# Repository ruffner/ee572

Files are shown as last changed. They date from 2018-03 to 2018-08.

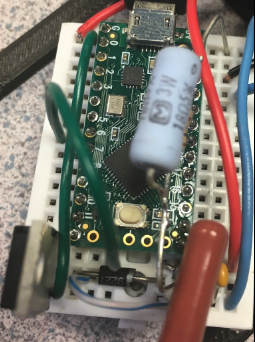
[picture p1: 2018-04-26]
project/Images/pic2.png

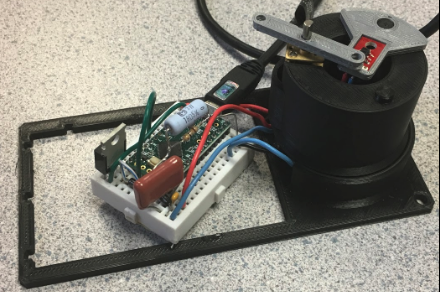
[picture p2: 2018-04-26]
project/Images/pic1.png

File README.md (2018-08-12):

# ee572

Home for EE572 Coursework, Digital Control of Dynamic Systems at the University of Kentucky. 
- [READ WRITEUP](https://github.com/ruffner/ee572/blob/master/project/ee572-project.pdf)
- Created an embedded implementation of a PID compensator. The body design from the [feedback strobe](http://github.com/ruffner/feedback-strobe) was modified to have higher rotation speed.
- RPM calculation done with [infrared reflectance sensor](https://www.sparkfun.com/products/9453).
- Code available in writeup

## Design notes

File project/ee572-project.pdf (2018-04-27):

# EE572 Course Project

### Matt Ruffner Alex Mueller Ben Cummins Galvin Greene

### April 27, 2018

## 1 Objective

A physical control system allows the team to apply class concepts to the real world. These include continuous/discrete time modeling and compensation techniques. With a working system, the team has demon-strated competency in controls theory. For this project the team used a Teensy LC 1 ARM microcontroller to implement a PID compensator. The system manages the speed of a DC motor with a propeller like attachment. Simulations were run in MATLAB to help design the PID compensator.

## 2 Continuous Time System

In order to fully control our chosen system, the team first had to analyze and decide on a G(s) model that would represent the system. The team had brief discussion and the chosen model can be seen from equation 1.

G(s) = K
1 + 0.5τs

(1)

Within this model, K represents the max speed, in RPM, that our motor can physically move, represents the time it took to move from the lowest to the highest. These variables were found by testing and measuring the system. Now that the G(s) has been determined, the team had to create a Zero Order Hold model for our system, which can be seen from equation 2

GZOH(s) = 1 1 + sTs

2

(2)

This representation for the Zero Order Hold is used to properly model the system in continuous time and simulate the discrete measurements. This model relies on a Ts and was chosen to be .1 seconds. The final model needed for the system is a compensation model to allow the team to alter the system to specific specs. For this the team chose a PID model and can be seen from equation 3

GP ID(s) = Ki + sKp + s

2Kd
| s

(3)

This model for the PID compensation requires the team to solve for Ki
, Kp, and Kd and is completed by determining an s1 that meets given transient specs and finding a Zc and a Kc by computing coefficients. For this model we used equation 4, because the team had no steady state error specs and thus could improve transient specs.

1https://www.pjrc.com/teensy/teensyLC.html

1

GP ID(s) = s

2Kc + 2sZcKc + KcZ

2
c

(4)

Where
Kd = Kc

Kp = 2KcZc

Ki = KcZ

2
c
Once these values were calculated and implemented into the equation, the team could then close the loop for the continuous time model by using equation 5. This is an important part of simulation as it shows how the system should react in real time and whether the transient specs were truly met and if needed, further optimized.

Gclosedloop(s) = GP ID(s)GZOH(s)G(s)
1 + GP ID(s)GZOH(s)G(s)

(5)

Additionally, if observed from the top level, the system would appear as Figure 1.

Figure 1: Continuous time system model

For a complete list of our given specs and those values that were solved for/calculated in MATLAB, see Table 1.

Parameter | Value
Ts | 0.1 seconds
τ | 8 seconds
Mp | 4.32%
ts | 1 second
s1 | -4+j3.996
K | 810
ωnζ | 4
ωn | 5.6566
ζ | 0.707
6 def. | 103.314◦
Zc | 7.1739
Kc | 0.0334
Ki | 1.7173
Kp | 0.4787
Kd | 0.0334

Table 1: System parameters

2

## 3 Discrete Time Compensator

The discrete compensator was found by using continuous version and substituting an estimate for s in terms of z. Our estimate was
s =

z − 1
zTs
which is a rectangular approximation from the right side. The bilinear transform was not used because it would have placed a pole at z = −1 when substituting in s with the Kd term. Using MATLAB we found

HP ID(z) = 3.546e17z

2 − 4.129e17z + 1.202e17
3.603e17z

2 − 3.603e17z
Simplifying the coefficients gives values of a0 = 1, a1 = −1, a2 = 0, b0 = 0.9842, b1 = −1.1461, b2 = 0.3337 for our second order filter to be implemented in microcontroller code.

## 4 MATLAB Simulation

This section contains plots of simulation data from designing the system in MATLAB.
Figure 2 shows the system’s step response before compensation. Figure 3 shows the step response of the compensated system.
Figure 4 shows the system’s step response before compensation. Figure 5 shows the step response of the compensated system.

## 5 Implementation

A simple geared down DC brushed motor is driven by a the Teensy LC microcontroller over USB power. Flyback diodes for reverse EMF protection and noise filtering circuitry are also included.
The second order PID filter was implemented the same way that was taught in EE572 lecture. The general form of the filter is shown in Equation 6.

Y (z)
W(z)

=

b0 + b1z

−1 + b2z

−2
a0 + a1z⁻¹ + a2

−2
z

(6)

The coefficients were computed in MATLAB, but taking the inverse z transform and rearranging to solve for yk, our output, gave a new equation that could be written in code:

yk=(b0*wk+b1*wk_minus1+b2*wk_minus2-a1*yk_minus1-a2*yk_minus2)/(a0)

Update equations were also needed to change the values after each iteration. These were as follows:

wk=Setpoint-rpm;
wk_minus2=wk_minus1;
wk_minus1=wk;
yk_minus2=yk_minus1;
yk_minus1=yk;

### 5.1 Feedback

Feedback on the rotation speed of the system is provided by an IR reflectance sensor. When the propeller passes over the sensor the output voltage dips. These dips are monitored with an ADC channel and detected with thresholding logic in software. The interrupt routine responsible for accurately determining the current RPM of the motor has a much high sampling rate than the control system that uses this information.

3

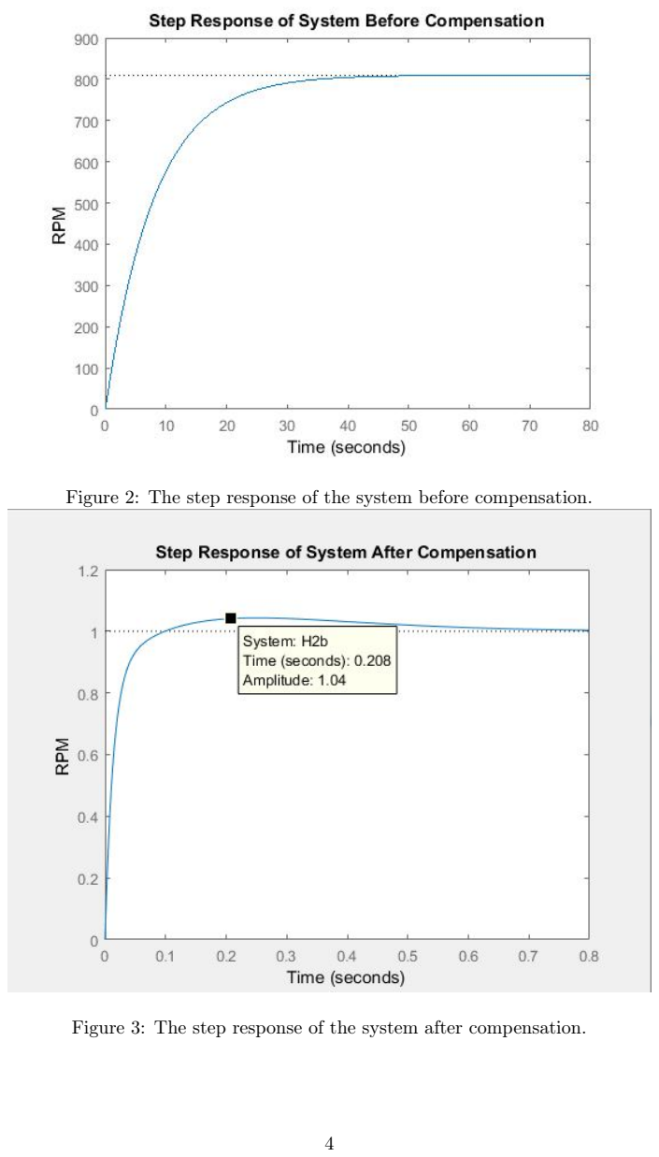
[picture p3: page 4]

Figure 2: The step response of the system before compensation.

Figure 3: The step response of the system after compensation.

4

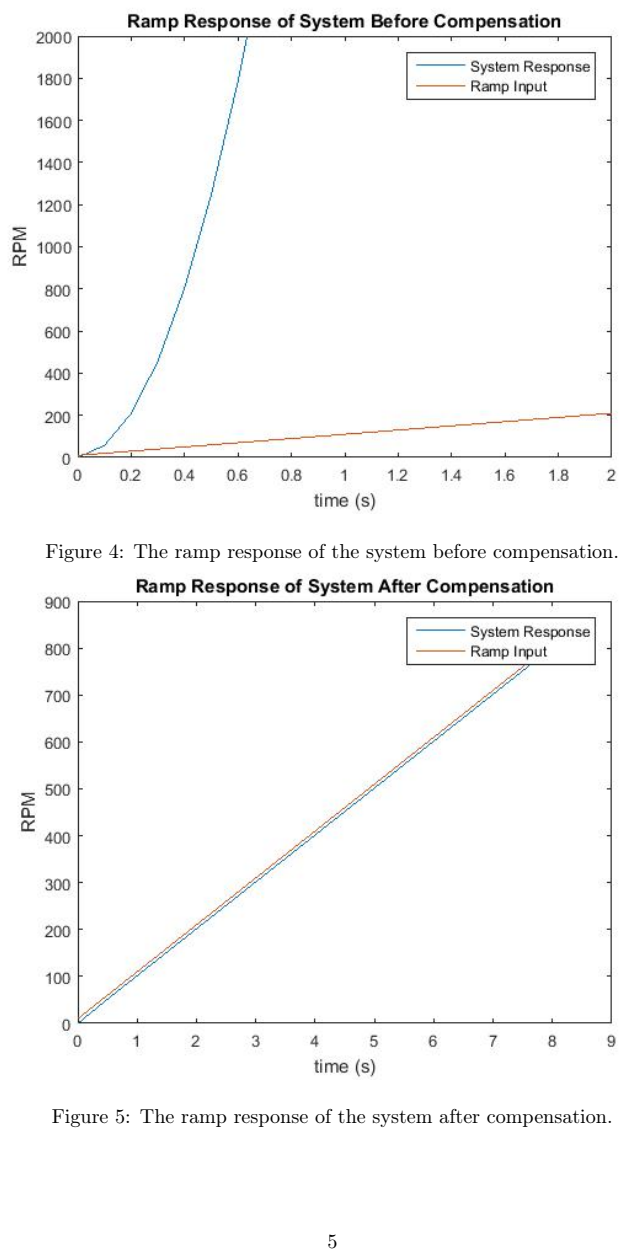
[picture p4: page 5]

Figure 4: The ramp response of the system before compensation.

Figure 5: The ramp response of the system after compensation.

5

The protection circuity was modified from the schematic seen in Figure 6

2 and only includes one MOS-FET.

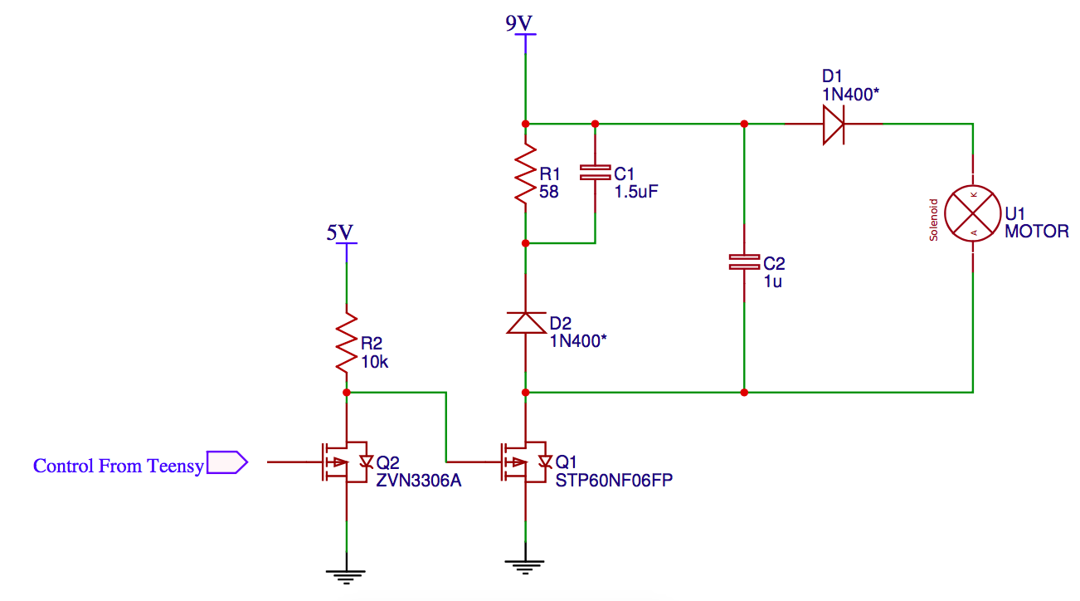
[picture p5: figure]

Figure 6: Back EMF protection circuitry.

### 5.2 Mechanical Design

One key aspect of the code was taking input from the analog reflectance sensor to compute the current RPM of the system. This was achieved by calling the millis() function in conjunction with interrupts from the TimerOne library. RPM values calculated using this method were used as part of the feedback of the system to compare to the setpoint.

### 5.3 Finished System

### 5.4 Plot of Compensation during Setpoint Change

The plot in Figure 8 shows a plot of the desired speed in comparison to the set speed with data logged from the device. This verifies the desired 1 second settling time that we improved from the original settling time of over ten seconds.
The plot in Figure 9 shows the Wk and Yk values during the same run as in Figure 8.

### 5.5 Plot of Compensation During Loading Down of Motor

Figures 10 and 11 show the response of the device under loading conditions e.g. hand on motor shaft. The plot in Figure 9 shows the Wk and Yk values during the same run as in Figure 8.

### 5.6 Ramp Following

Figure 12 shows the real system following a ramp.

2github.com/ruffner/feedback-strobe

6

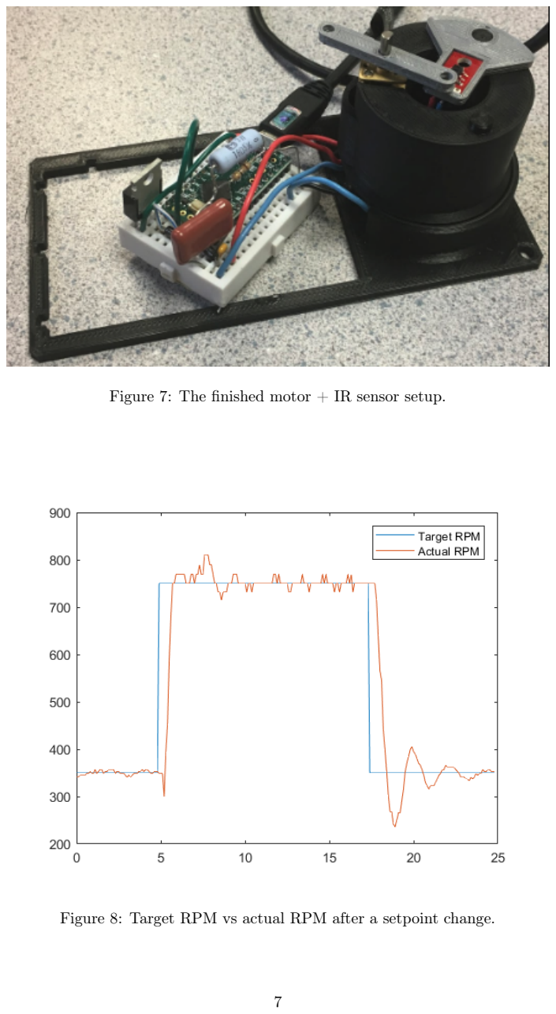
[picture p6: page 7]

Figure 7: The finished motor + IR sensor setup.

Figure 8: Target RPM vs actual RPM after a setpoint change.

7

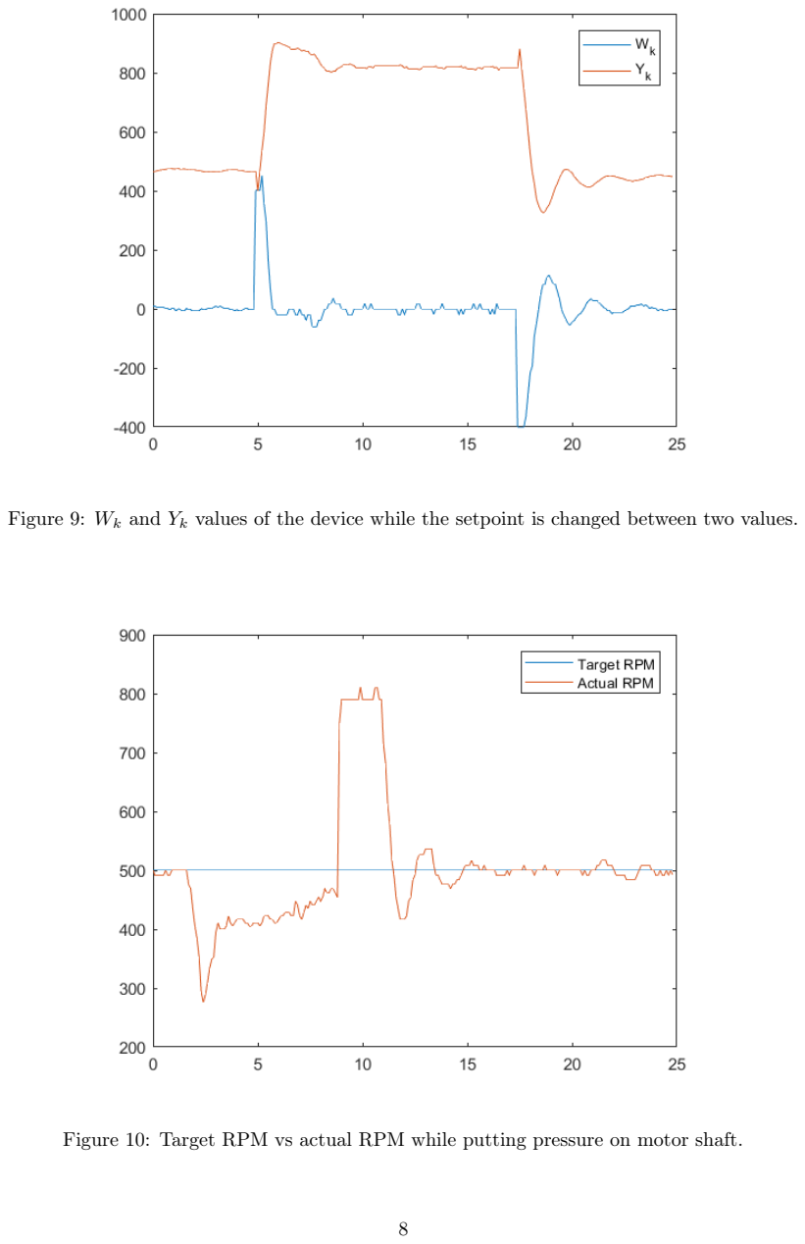
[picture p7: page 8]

Figure 9: Wk and Yk values of the device while the setpoint is changed between two values.

Figure 10: Target RPM vs actual RPM while putting pressure on motor shaft.

8

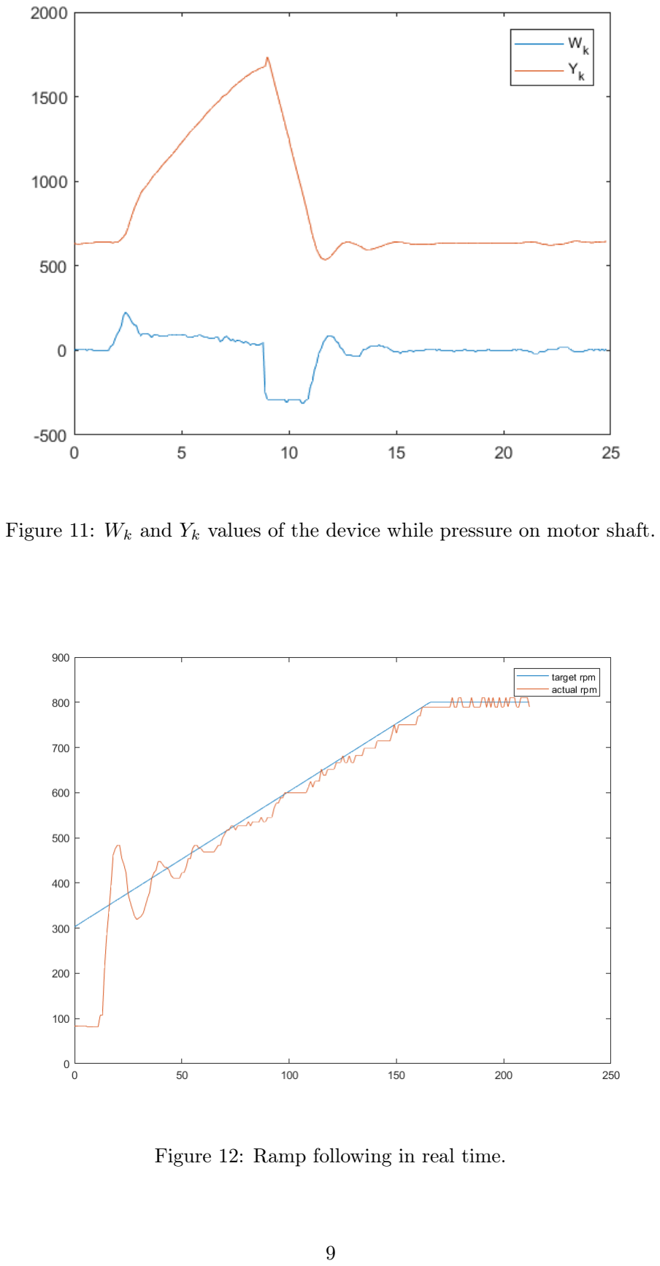
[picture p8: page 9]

Figure 11: Wk and Yk values of the device while pressure on motor shaft.

Figure 12: Ramp following in real time.

9

## 6 Contributions

### 6.1 Alex Mueller

Preliminary brainstorming and MATLAB Code.

### 6.2 Matt Ruffner

Mechanical design, Arduino coding.

### 6.3 Benjamin Cummins

MATLAB coding and brainstorming.

### 6.4 Galvin Greene

Debugged MATLAB and Arduino code.

## 7 References

Code can be found at: https://github.com/ruffner/ee572/tree/master/project

## 8 Arduino Code

// EE572 control system
// Matt Ruffner
// Alex Mueller
// Ben Cummins
// Galvin Greene

#include <TimerOne.h>

#define IRPIN A9

#define MOTOR 6

// MOTOR PWM VALUES WERE ITERATED THROUGH, WITH THE CORRESPONDING RESULTING // RPM VALUE LOGGED. THESE VALUES WERE LOADED INTO MATLAB AND FIT WITH A // POLYNOMIAL. THE FOLLOWING ARRAY IS THE POLYNOMIAL EVALUATED AT VARIOUS // PWM VALUES TO GET A SMOOTHER SPEED CURVE.
// CODE TO GENERATE THIS TABLE CAN BE FOUND IN speed_fit.m in the
// EE572 REPOSITORY

PROGMEM float RPMMap[175] = { 2.847108e+02,2.918626e+02,2.989418e+02,3.059491e+02,3.128849e+02, 3.197497e+02,3.265440e+02,3.332684e+02,3.399233e+02,3.465093e+02, 3.530267e+02,3.594762e+02,3.658583e+02,3.721733e+02,3.784219e+02, 3.846046e+02,3.907218e+02,3.967740e+02,4.027618e+02,4.086856e+02, 4.145460e+02,4.203434e+02,4.260784e+02,4.317514e+02,4.373630e+02, 4.429136e+02,4.484038e+02,4.538341e+02,4.592049e+02,4.645168e+02, 4.697702e+02,4.749657e+02,4.801038e+02,4.851849e+02,4.902096e+02, 4.951784e+02,5.000917e+02,5.049501e+02,5.097541e+02,5.145042e+02,

10

5.192008e+02,5.238446e+02,5.284359e+02,5.329753e+02,5.374632e+02, 5.419003e+02,5.462870e+02,5.506237e+02,5.549110e+02,5.591495e+02, 5.633395e+02,5.674816e+02,5.715763e+02,5.756241e+02,5.796255e+02, 5.835810e+02,5.874911e+02,5.913564e+02,5.951772e+02,5.989541e+02, 6.026877e+02,6.063783e+02,6.100266e+02,6.136330e+02,6.171979e+02, 6.207221e+02,6.242058e+02,6.276496e+02,6.310541e+02,6.344197e+02, 6.377469e+02,6.410363e+02,6.442882e+02,6.475033e+02,6.506821e+02, 6.538249e+02,6.569324e+02,6.600051e+02,6.630433e+02,6.660478e+02, 6.690188e+02,6.719570e+02,6.748628e+02,6.777368e+02,6.805794e+02, 6.833912e+02,6.861726e+02,6.889242e+02,6.916464e+02,6.943398e+02, 6.970049e+02,6.996421e+02,7.022519e+02,7.048349e+02,7.073916e+02, 7.099224e+02,7.124279e+02,7.149086e+02,7.173649e+02,7.197974e+02, 7.222066e+02,7.245930e+02,7.269570e+02,7.292992e+02,7.316201e+02, 7.339201e+02,7.361999e+02,7.384598e+02,7.407004e+02,7.429222e+02, 7.451256e+02,7.473113e+02,7.494796e+02,7.516312e+02,7.537664e+02, 7.558858e+02,7.579900e+02,7.600793e+02,7.621543e+02,7.642155e+02, 7.662634e+02,7.682985e+02,7.703214e+02,7.723324e+02,7.743322e+02, 7.763211e+02,7.782998e+02,7.802686e+02,7.822282e+02,7.841790e+02, 7.861216e+02,7.880563e+02,7.899838e+02,7.919044e+02,7.938189e+02, 7.957275e+02,7.976308e+02,7.995294e+02,8.014237e+02,8.033143e+02, 8.052016e+02,8.070861e+02,8.089683e+02,8.108488e+02,8.127280e+02, 8.146065e+02,8.164847e+02,8.183632e+02,8.202424e+02,8.221228e+02, 8.240050e+02,8.258894e+02,8.277766e+02,8.296671e+02,8.315613e+02, 8.334597e+02,8.353629e+02,8.372714e+02,8.391856e+02,8.411061e+02, 8.430334e+02,8.449679e+02,8.469102e+02,8.488608e+02,8.508201e+02, 8.527887e+02,8.547670e+02,8.567557e+02,8.587551e+02,8.607658e+02, 8.627883e+02,8.648230e+02,8.668706e+02,8.689314e+02,8.710060e+02 };

// VARS FOR DETERMINING CURRENT RPM
unsigned long lastFreqUpdate = 0; float rpm = 0;
int state = 0;
unsigned long lastLowTime = 0; volatile unsigned long diffTime = 0;

// CONTROL PARAMETER
double Setpoint;

// PID STATE VARS
float yk=0.0;
float yk_minus1=0.0;
float yk_minus2=0.0;
float wk=0.0;
float wk_minus1=0.0;
float wk_minus2=0.0;

// PID TF COEFFICIENTS
float b0=0.9842;
float b1=-1.1461;
float b2=0.3337;

11

float a0=1.0;
float a1=-1.0;
float a2=0.0;

unsigned long startTime = 0;

void setup() {
// PIN DIRECTION DEFINITIONS pinMode(IRPIN, INPUT);
pinMode(MOTOR, OUTPUT);
pinMode(13, OUTPUT); // LED

Serial.begin(115200);
delay(2000);

// RPM SENSING SETUP
// 1 MILLISECOND SAMPLING PERIOD REQUIRED // TO GET ACCURATE RPM SENSING Timer1.initialize(1000);
// ISR CALLBACK
Timer1.attachInterrupt(checkSensor); // TIMESTAMP FOR RPM SENSING lastLowTime = millis();

// INITIAL LOW MOTOR SPEED analogWrite(MOTOR, 80);

unsigned long n=millis();
while(millis()-n < 1000){
digitalWrite(13, HIGH);
delay(100);
digitalWrite(13, LOW);
delay(100);
}

// INITIAL TARGET RPM OF 300 Setpoint = 300;

wk=rpm;

startTime = millis();
}

// 3 STATE THRESHOLD BASED RPM SENSING FOR // ANALOG REFLECTANCE SENSOR
void checkSensor() {
int val = analogRead(IRPIN) >> 5;
if( state == 0 ){
if( val < (600 >> 5) ){
state = 1;

12

}
} else if( state == 1) {
if( val > (700>>5) ){
lastLowTime = millis();
state = 2;
}
} else if( state == 2) {
if( val < (600>>5) ){
diffTime = millis() - lastLowTime; state = 0;
}
}
}

void loop() {

// RUN CODE INSIDE THIS IF EVERY 100 MILLISECONDS (Ts) if( millis() - 100 > lastFreqUpdate ){
if( Serial.available() ){
Setpoint = Serial.parseInt();
}

// UNCOMMENT TO FOLLOW A RAMP
// Setpoint = Setpoint + 3;
// if( Setpoint > 800 ) Setpoint = 800;

// UPDATE TIMESTAMP TO KEEP TRACK OF Ts lastFreqUpdate = millis();
unsigned long temp = 0;
// ATOMIC READ OF VOLATILE VARIABLE INSIDE ISR noInterrupts();
temp = diffTime;
interrupts();

// COMPUTE CURRENT RPM
rpm = 1.0/(2.0*(float)(diffTime)*0.001) * 60;

// COMPUTE THE OUTPUT
yk=(b0*wk+b1*wk_minus1+b2*wk_minus2-a1*yk_minus1-a2*yk_minus2)/(a0);

// SET THE INPUT
wk=Setpoint-rpm;

double targetRPM = yk;

// TAB DELIMITTED SERIAL LOGGING FOR PLOTTING IN MATLAB Serial.print(Setpoint);Serial.print("\t"); Serial.print(rpm);Serial.print("\t"); Serial.print(wk);Serial.print("\t"); Serial.println(yk);

13

// LOOKUP TARGET RPM
for( int i=0;i<174;i++ ){
if( RPMMap[i] <= targetRPM && RPMMap[i+1] > targetRPM ){ // DRIVE MOTOR AT NEW SPEED
analogWrite(MOTOR, i+81);
}
}

// UPDATE INPUT/OUTPUT STATE VARIABLES wk_minus2=wk_minus1;
wk_minus1=wk;
yk_minus2=yk_minus1;
yk_minus1=yk;
}

}

## 9 Simulation Code

% Alex Mueller
% Galvin Greene, Ben Cummins, Matt Ruffner
% EE 572 Final Project Simulation

% Purpose: To simulate our 1st order type zero system when
% subject to ramp and step inputs. Also we wish to compute PID parameters
% and discrete time compensator filter parameters
% to form the compensated system for simulation and programing of the system.

close all

syms s

%motor parameters
k = 810; % dc gain (max of 810 rpm)
tau = 8; % time constant ( time to get to .632 of max speed)

Ts = .1; % sampling time

Mp = 4.32; % max percent overshoot m = Mp/100;

% compute zeta based on given specs zeta = -log(m)/sqrt((pi^2)+log(m)^2);

ts = 1; % desired settling time (seconds) wnzeta = 4/ts;
wn = wnzeta/zeta;

% define system and compensator functions

14

gzoh = 1/(1+(Ts/2)*s);
g = k/(1+tau*s);

% desired dominant closed-loop pole
s1 = -wnzeta + 1i*wn*sqrt(1-(zeta^2));

% find transfer function of the system before compensation H1a = gzoh*g;
H1b = syms2tf(H1a);

% simulate uncompensated system step response step(H1b)
title(’Step Response of System Before Compensation’) ylabel(’RPM’)

%generate a ramp input
len =85;
u1 = ones(1,len);
for i = 1:len
u1(i) = 10*i*u1(i);
end
t = 0:Ts:Ts*len-Ts;
x0 = 0;

% simulate uncompensated system with the ramp input y = lsim(H1b,u1,t,x0,’zoh’);

% plot simulation
figure
plot(t,y,t,u1)
ylim([-.1 2000])
xlim([0 2])
legend(’System Response’,’Ramp Input’)
title(’Ramp Response of System Before Compensation’) ylabel(’RPM’)

s = s1;
gzohg = double(abs(subs(g*gzoh/s1)));
ang_def = 180-((180*angle(double(subs(g)*subs(gzoh))/s1)/pi)); half_ang = ang_def/2;
Zc = (imag(s1)/tan(half_ang*pi/180))-real(s1);
Kc = 1/(abs(s1+Zc)^2+gzohg);
Kd = Kc;
Ki = Kc*Zc^2;
Kp = 2*Zc*Kc;

syms s

% symbolic pid function
gpid = (Ki+Kp*s+Kd*s^2)/s;

15

% find closed-loop transfer function of the compensated system H2a = (gzoh*g*gpid)/(1+gzoh*g*gpid);
H2b = syms2tf(H2a);

% simulate compensated system step response figure
step(H2b)
title(’Step Response of System After Compensation’) ylabel(’RPM’)

% simulate compensated system ramp response
y2 = lsim(H2b,u1,t,x0,’zoh’);
% plot simulation
figure
plot(t,y2,t,u1)
legend(’System Response’,’Ramp Input’)
title(’Ramp Response of System After Compensation’) ylabel(’RPM’)

% discretize system
syms z
s = (z-1)/(z*Ts); % use rectanglar estimation holding from right side H_z = subs(gpid);
[symNum,symDen] = numden(H_z); %Get num and den of Symbolic TF
TFnum = sym2poly(symNum); | %Convert Symbolic num to polynomial
TFden = sym2poly(symDen); | %Convert Symbolic den to polynomial
H_z_tf =tf(TFnum,TFden,Ts);
[num,den,Ts1] = tfdata(H_z_tf,’v’);

factor = den(1);

den = [den 0];

num = num/factor;
den = den/factor;

% assign filter coefficients b0 = num(1);
b1 = num(2);
b2 = num(3);
a0 = den(1);
a1 = den(2);
a2 = den(3);

% Convert Symbolic Transfer Function to ZPK Transfer Function
% Crystal Nassouri 2009
% Allows for substitution/manipulation that can only be done with syms %

16

% Ex: Gs = syms2tf(G)
% Where G is a symbolic equation and Gs is a zpk transfer function

function[ans] = syms2tf(G)
[symNum,symDen] = numden(G); %Get num and den of Symbolic TF
TFnum = sym2poly(symNum); | %Convert Symbolic num to polynomial
TFden = sym2poly(symDen); | %Convert Symbolic den to polynomial
ans =tf(TFnum,TFden);

17

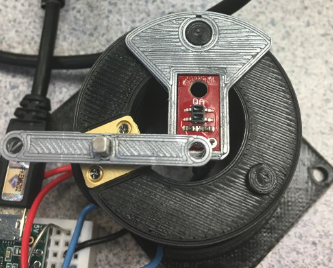
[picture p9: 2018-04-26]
project/Images/pic3.png

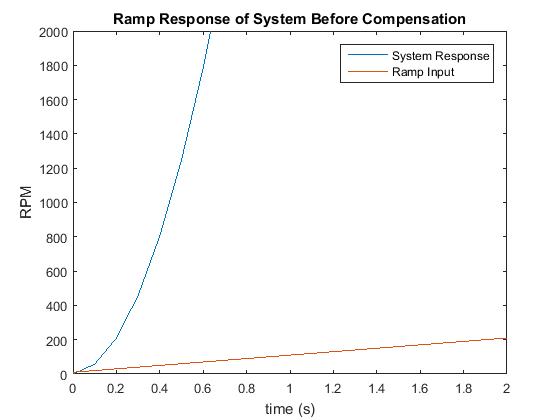
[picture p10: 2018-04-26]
project/Images/ramp_before_comp.jpg

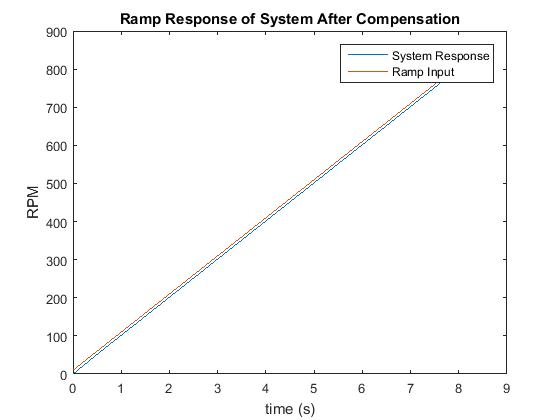
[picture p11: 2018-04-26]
project/Images/ramp_after_comp.jpg

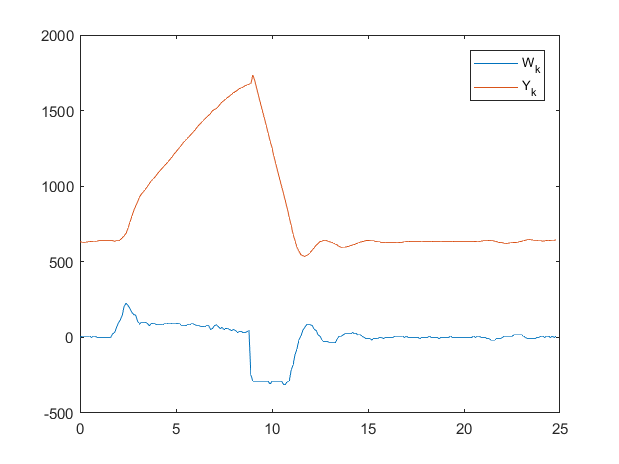
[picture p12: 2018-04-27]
project/Images/compyk.png

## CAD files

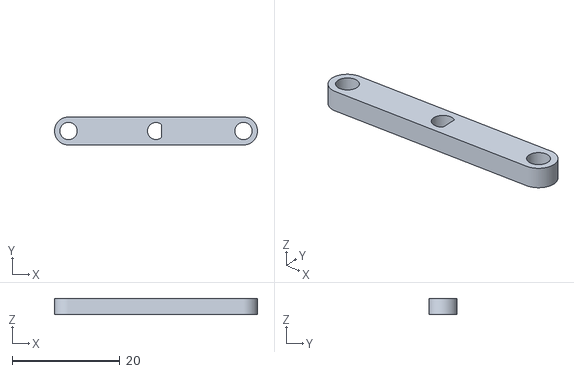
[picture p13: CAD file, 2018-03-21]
project/cad/stl/spinner.stl
37.6 x 5.20 x 3.00

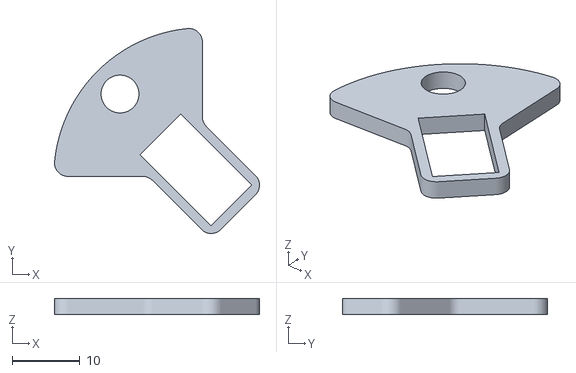
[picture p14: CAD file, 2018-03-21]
project/cad/stl/ir-holder.stl
30.4 x 30.4 x 2.40

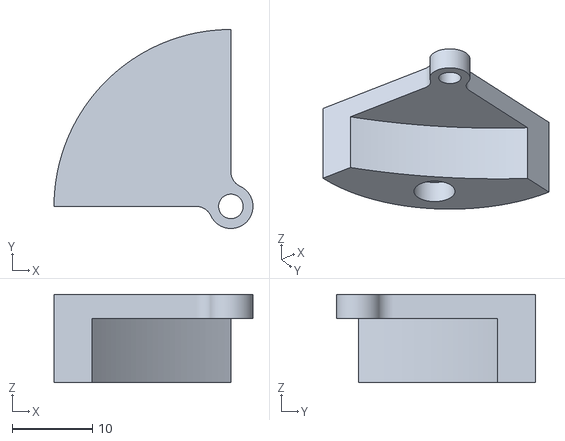
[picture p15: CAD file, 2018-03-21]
project/cad/stl/led-holder.stl
24.7 x 24.7 x 11.0

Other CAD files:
project/cad/ir-holder.ipt
project/cad/led-holder.ipt
project/cad/spinner.ipt

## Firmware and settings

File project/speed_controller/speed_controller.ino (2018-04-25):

// ee572 control system
// mr gg am bc

#include <TimerOne.h>
#include <PID_v1.h>

#define IRPIN A9
#define MOTOR 6

PROGMEM float RPMMap[175] = {
/* 81 */ 187.36,
/* 82 */ 191.60,
/* 83 */ 207.32,
/* 84 */ 220.47,
/* 85 */ 228.35,
/* 86 */ 229.12,
/* 87 */ 247.24,
/* 88 */ 256.46,
/* 89 */ 268.24,
/* 90 */ 272.73,
/* 91 */ 273.73,
/* 92 */ 272.73,
/* 93 */ 295.95,
/* 94 */ 308.99,
/* 95 */ 322.32,
/* 96 */ 335.75,
/* 97 */ 349.69,
/* 98 */ 357.72,
/* 99 */ 372.74,
/* 100 */ 372.22,
/* 101 */ 377.39,
/* 102 */ 377.39,
/* 103 */ 386.16,
/* 104 */ 407.86,
/* 105 */ 406.53,
/* 106 */ 409.85,
/* 107 */ 424.58,
/* 108 */ 431.06,
/* 109 */ 430.43,
/* 110 */ 438.90,
/* 111 */ 461.69,
/* 112 */ 449.12,
/* 113 */ 449.80,
/* 114 */ 477.49,
/* 115 */ 478.49,
/* 116 */ 483.13,
/* 117 */ 491.09,
/* 118 */ 503.42,
/* 119 */ 493.44,
/* 120 */ 490.22,
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


unsigned long lastFreqUpdate = 0;

float rpm = 0;
int state = 0;
unsigned long lastLowTime = 0;
volatile unsigned long diffTime = 0;

// PID PARAMETERS
//Define Variables we'll be connecting to
double Setpoint, Input, Output;

//Define the aggressive and conservative Tuning Parameters
double aggKp=4, aggKi=0.2, aggKd=1;
double consKp=1, consKi=0.05, consKd=0.25;

//Specify the links and initial tuning parameters
PID myPID(&Input, &Output, &Setpoint, .0375, .1486, .0024, DIRECT);

void setup() {
  // put your setup code here, to run once:
  pinMode(A9, INPUT);
  pinMode(6, OUTPUT);

  Serial.begin(115200);
  delay(2000);

  Timer1.initialize(1000);
  Timer1.attachInterrupt(checkSensor);
  lastLowTime = millis();

  
  analogWrite(MOTOR, 80);

  unsigned long n=millis();
  while(millis()-n < 1000){
    digitalWrite(13, HIGH);
    delay(100);
    digitalWrite(13, LOW);
  }


  //initialize the variables we're linked to
  Input = map(rpm,200,800,0,255);
  Setpoint = map(300,200,800,0,255); // target rpm=500

  //turn the PID on
  myPID.SetMode(AUTOMATIC);
  
}

void checkSensor() {
  int val = analogRead(IRPIN) >> 5;
  if( state == 0 ){
    if( val < (600 >> 5) ){
      state = 1;
    }
  } else if( state == 1) {
    if( val > (700>>5) ){
      lastLowTime = millis();
      state = 2;
    }
  } else if( state == 2) {
    if( val < (600>>5) ){
      diffTime = millis() - lastLowTime;
      state = 0;
    }
  }
}


void loop() {

  if( millis() - 100 > lastFreqUpdate ){
    if( Serial.available() ){
      //analogWrite(MOTOR, Serial.parseInt());
      int v = Serial.parseInt();
      Setpoint = map(v,200,800,0,255);
      Serial.print("New setpoint(rpm):");
      Serial.println(v);
      Serial.print("New setpoint (mapped): ");
      Serial.println(Setpoint);
    }
  
    lastFreqUpdate = millis();
    unsigned long temp = 0;
    noInterrupts();
    temp = diffTime;
    interrupts();
  
    float rotFreq = 1.0/(2.0*(float)(diffTime)*0.001);
    rpm = rotFreq * 60;

    Serial.println();

    Serial.print("Target: ");
    Serial.println(Setpoint);
    Serial.print("Target rpm: ");
    Serial.println(map(Setpoint,0,255,200,800));
    
    Serial.print("Current rpm: ");
    Serial.println(rpm);
  
    //if( abs(Input-rpm) <10 ){
      Input = map(rpm,200,800,0,255);
    //}
    
    double gap = abs(Setpoint-Input); //distance away from setpoint
    
   // if(gap<10) {  //we're close to setpoint, use conservative tuning parameters
      //myPID.SetTunings(consKp, consKi, consKd);
    //} else {
       //we're far from setpoint, use aggressive tuning parameters
    //   myPID.SetTunings(aggKp, aggKi, aggKd);
    //}
    
    myPID.Compute();

    double targetRPM = map(Output,0,255,200,800);

    Serial.print("new output: ");
    Serial.println(Output);
    Serial.print("mapped output: ");
    Serial.println(targetRPM);

    // find pwm associated with target rpm
    for( int i=0;i<174;i++ ){
      if( RPMMap[i] < targetRPM && RPMMap[i+1] > targetRPM ){
        analogWrite(MOTOR, i+80);
      }
    }
    
  }

}

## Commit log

2018-03-21 added initial project parts
    [ir-holder.ipt, ir-holder.stl, led-holder.ipt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]
2018-04-23 more work on pwm calibration
    [speedcal.tsv, speedcal2.tsv]
2018-04-25 put in pid values, system is workinggit status
    [speedcal.tsv, speedcal2.tsv]
2018-04-25 Add files via upload
    This one has the PID library taken out but isnt completely working. Tends towards ovf,inf
2018-04-26 updated no pid lib code
2018-04-26 updated to no pid library, working
2018-04-26 Images
    Images for the PID responses
2018-04-26 Rename Images to Test
    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
2018-04-27 added schematic and high level diagram
